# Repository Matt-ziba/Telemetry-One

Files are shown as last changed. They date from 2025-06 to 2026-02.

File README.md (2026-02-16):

## **Telemetry One** keyboard
*This is my submission for the second round of the HackPad YSWS event.*

#### Description:

The **Telemetry One** is a 75%, hot-swappable keyboard with an included accessory port (meant for a display but can be used for any I2C accessory :D ) and a case designed to fit into "sleeves", allowing for different looks while keeping the core the same. 

#### Design goal:

The main goal was to design a keyboard that I would actually like using, and that would follow a little bit of my design philosophy. I believe that as people, we grow and change over the years, and so should our equipment to better suit our needs and preferences. This idea, although not perfectly executed, is incorporated into the design of Telemetry One. The hot-swap sockets allow changing the switches at any point, so if I ever decide I no longer like tactile switches, and would rather switch to linear, I can do so! The I2C port, although very simple, allows for many different kinds of accessories to be connected to the keyboard. The ones that come to mind the most are things like displays, rotary encoders, haptic feedback, BLE modules for wireless connectivity or even connecting a macropad as an I2C slave device. The last important part is the case, which allows for mounting into different "sleeves", enabling the user to switch keyboard looks as they choose. Overall, I think I achieved my goal with the Telemetry One pretty well and I'm happy with how the design turned out.

#### Parts description:

The PCB itself is pretty decent, it also took the longest :D. The overall design isn´t too complex but I took my time really polishing it. I´m sure that I´ll find lots of flaws in it during assembly or during usage, but that´s just part of the process!

The case is pretty bare bones, but that is intentional. Instead of a full fledged case, I wanted something that could easily be mounted in different "sleeves" depending on the desired look. I have yet to model the "sleeve" designs I have in mind, but I do have a couple of ideas for them. The assembly of the case is pretty simple, with screws going from the bottom through the entirety of the case into the top part, which will have embedded nuts.

The firmware is absolute dogwater, that´s unfortunately not intentional :D. Yeah to be honest I procrastinated on the firmware until the last day and had to write it while hungover with not enough time to do proper research. I will definitely rewrite it once the keyboard actually arrives, as that will make debugging way easier. Currently it´s some weird ahh code that should probably work, but I honestly have no clue. 

## PCB Images

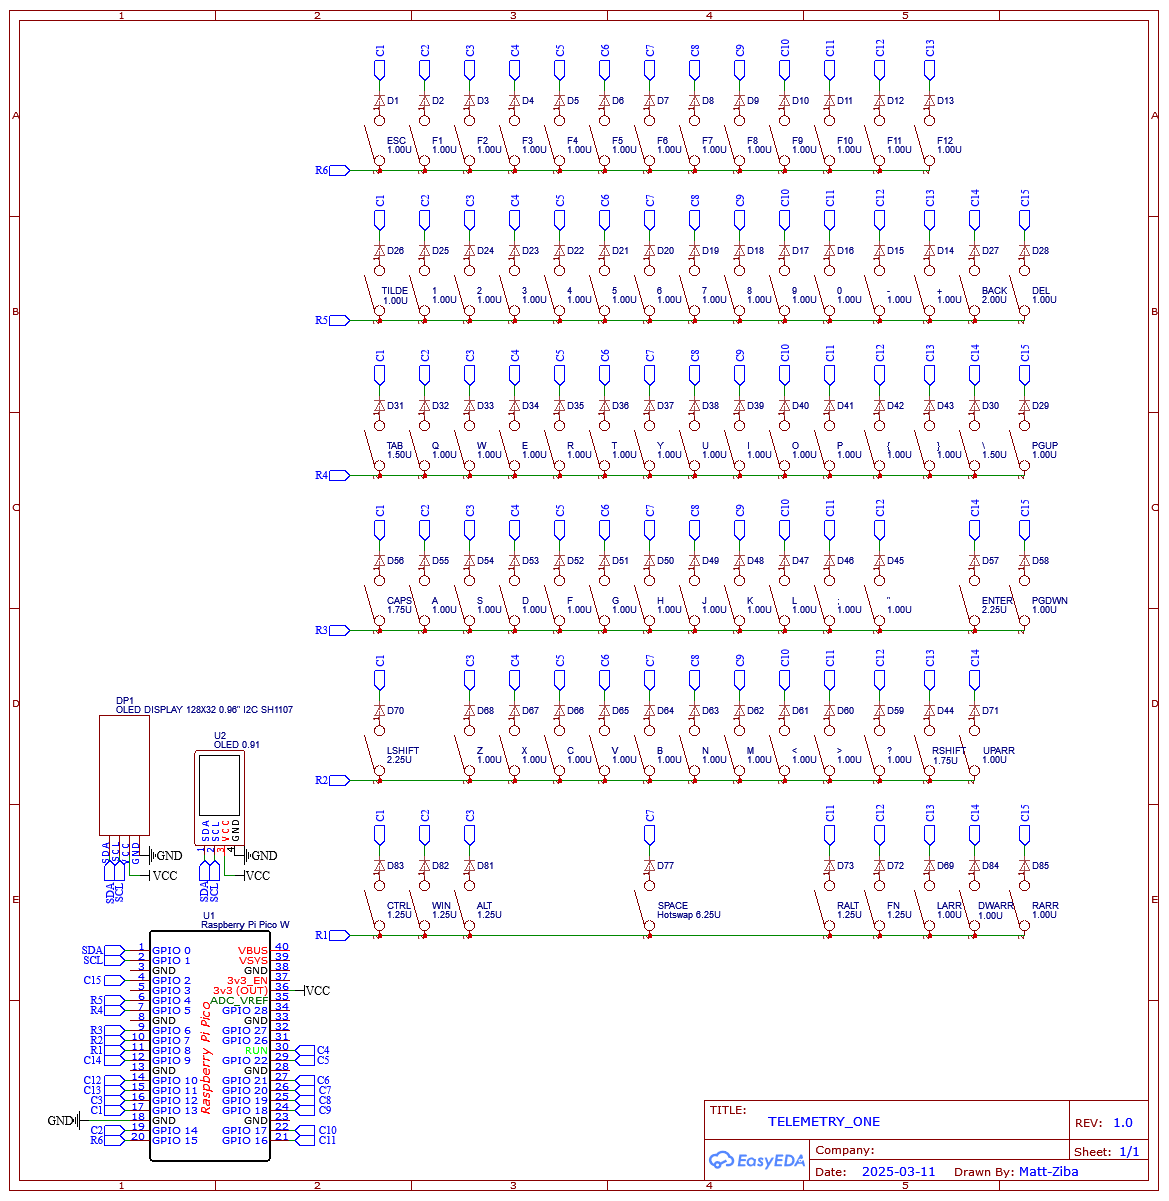
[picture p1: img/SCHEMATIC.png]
Schematic Screenshot

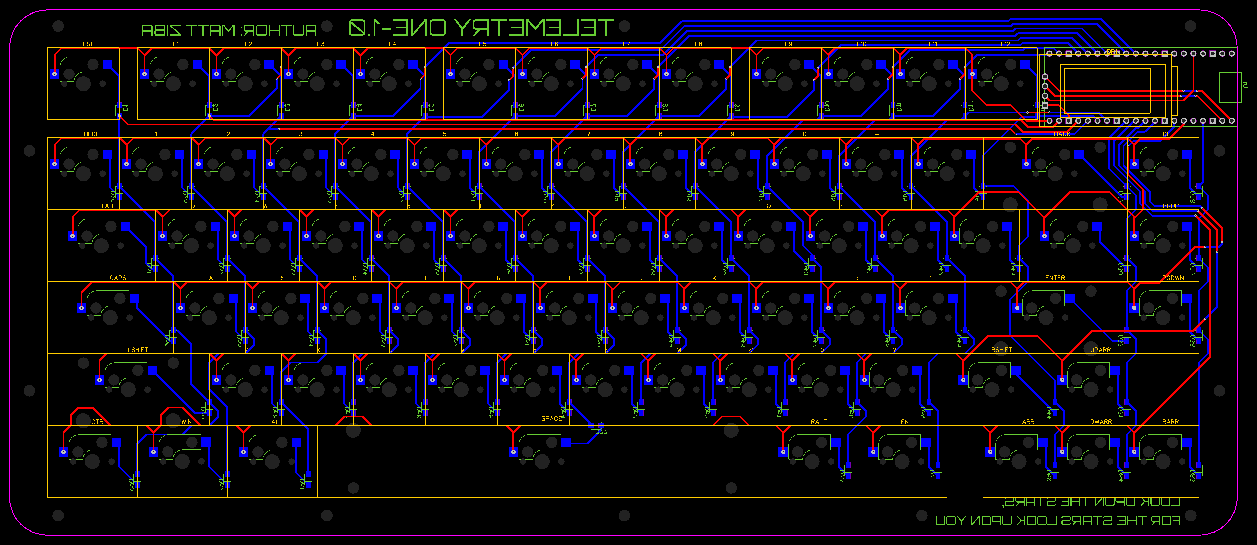
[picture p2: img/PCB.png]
PCB Screenshot

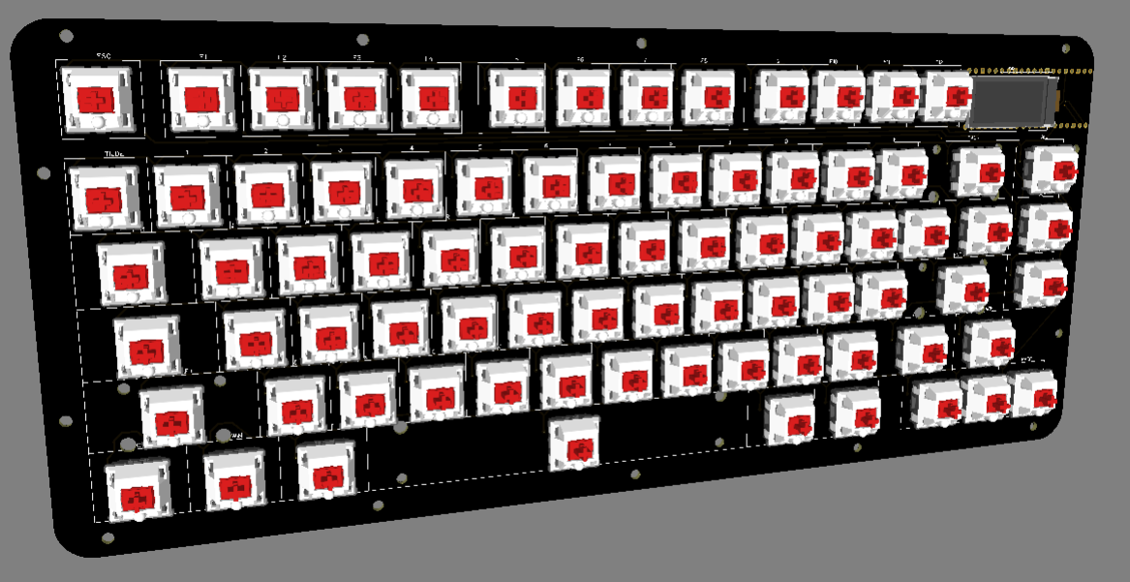
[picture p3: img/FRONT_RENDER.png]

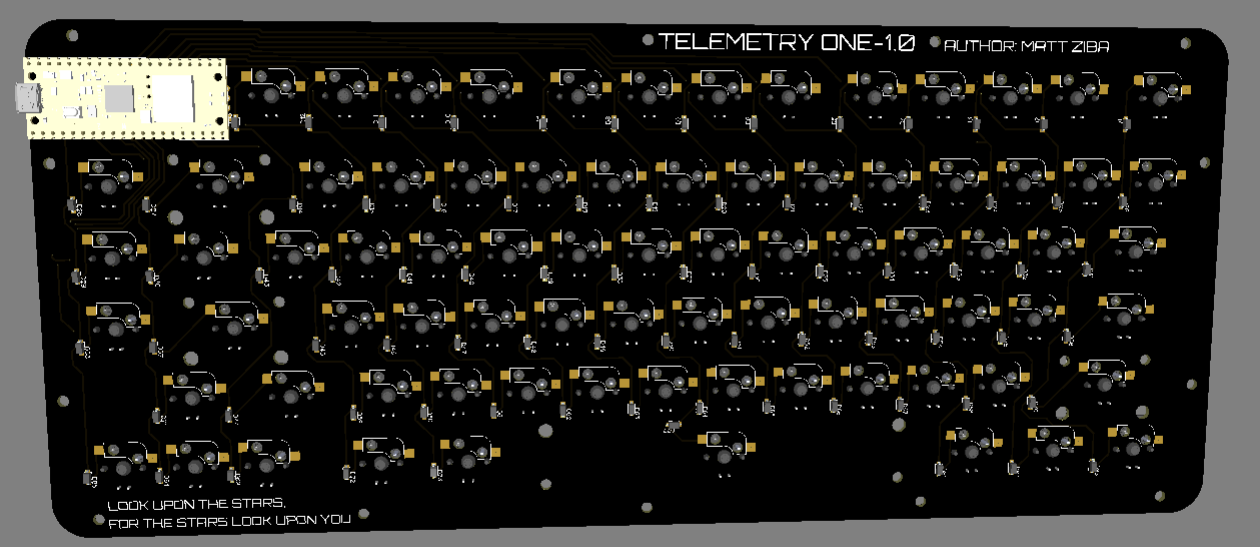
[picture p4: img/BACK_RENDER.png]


## Case Image

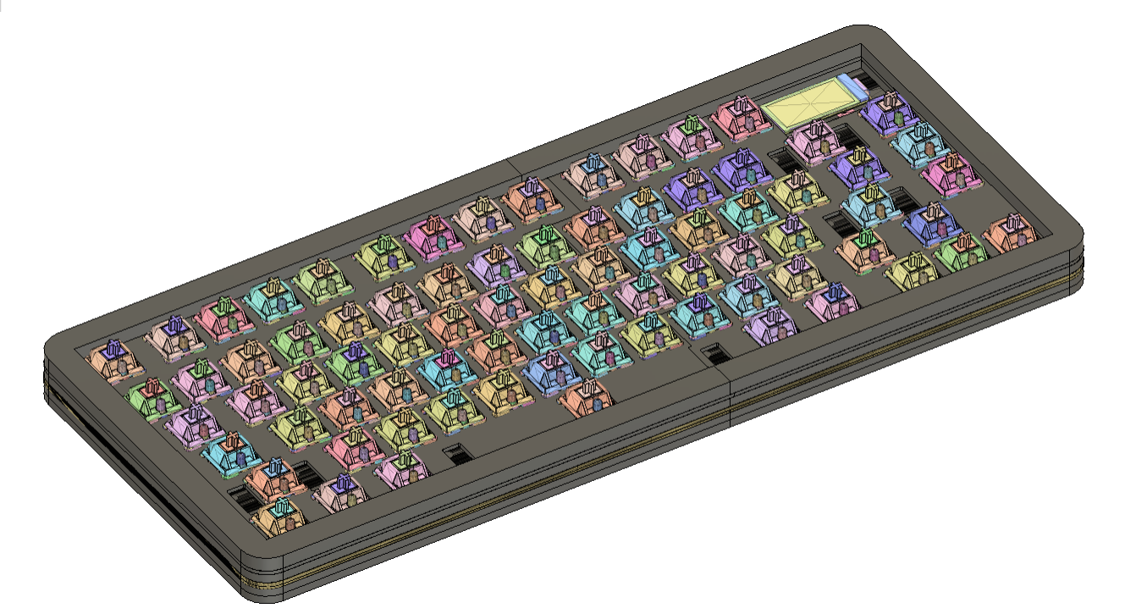
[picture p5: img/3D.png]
Case Screenshot


## BILL OF MATERIALS
| Item | Quantity | Price | Link |
|---|---|---|---|
| Akko V3 Creamy Blue Pro Switch | 1x 90pcs pack | 18USD (0.2USD per piece) | https://en.akkogear.com/product/akko-v3-cream-blue-pro-switch-45pcs/ |
| Kailh Hotswap sockets | 2x 50pcs pack | 16USD (0.16USD per piece) | https://splitkb.com/products/kailh-hotswap-sockets |
| TX AP stabilizers | 1x pack | 23USD (3USD over budget paid by me) | https://divinikey.com/products/tx-ap-stabilizers-rev-4 |
| Keycap Set from Aliexpress | 1x set | 22USD | https://www.aliexpress.com/item/1005007393936770.html |
| L1N4148 Diodes from LCSC | 2x 50pcs | 1.3USD (0.013USD per piece) | https://lcsc.com/product-detail/Switching-Diodes_LRC-L1N4148FT1G_C132821.html |
| 0.91" Display from LCSC | 1x | 2.3USD | https://lcsc.com/product-detail/OLED-Display_HS-HS91L02W2C01_C5248081.html |
| PCB | 1x (JLCPCB 5pcs minimum) | <20USD | N/A |
| Orpheus Pico board | 1x | N/A | N/A |

Materials cost in total: Around **100USD** (The materials in the BOM are a total 84USD, but I don't know how much the PCB will cost, or what the shipping costs will be, so I would rather have a little headroom)

I do not need the 3D printed parts, as I have access to a 3D printer and thus I don´t want to waste HackClub resources by requesting the parts when I can print them myself.  
I also don´t need fasteners, as I intentionally designed the keyboard around fasteners which I have at home.

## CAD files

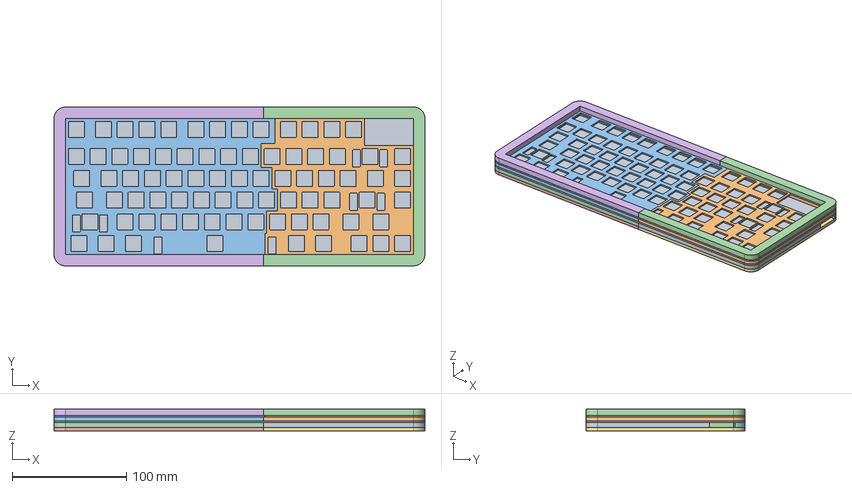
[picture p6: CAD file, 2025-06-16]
CAD/Telemetry_One.step
324.9 x 139.1 x 18.9 mm

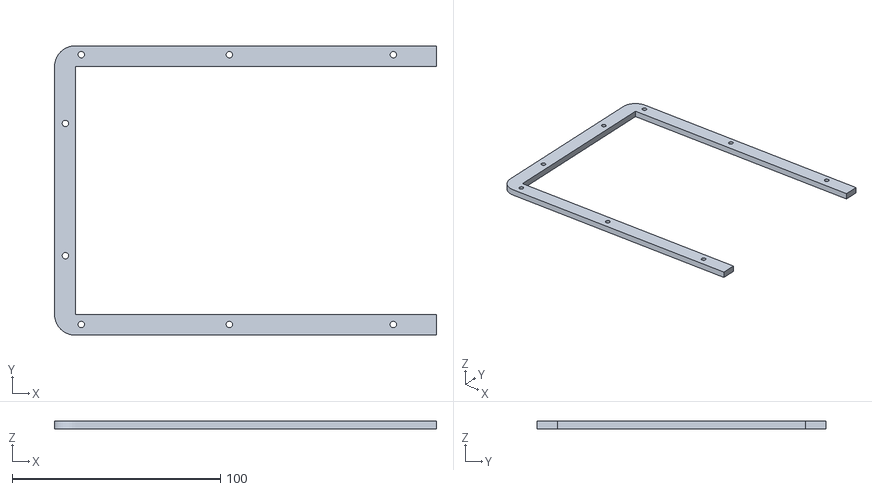
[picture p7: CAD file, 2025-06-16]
production/BOTSPACER.stl
183.4 x 139.0 x 4.00

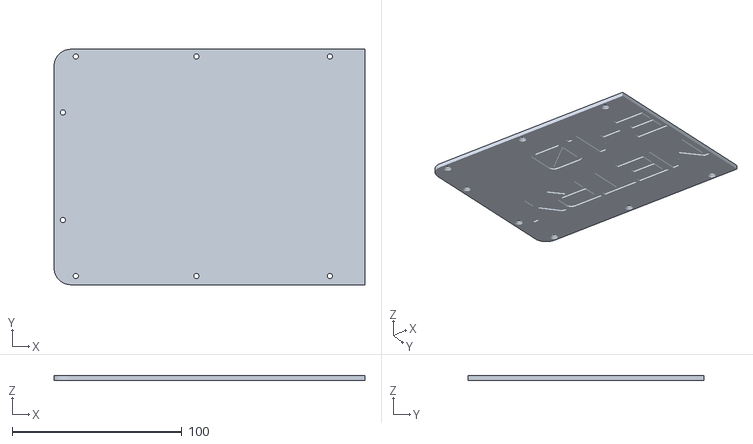
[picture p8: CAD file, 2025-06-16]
production/BOTPLATE.stl
183.4 x 139.0 x 3.10

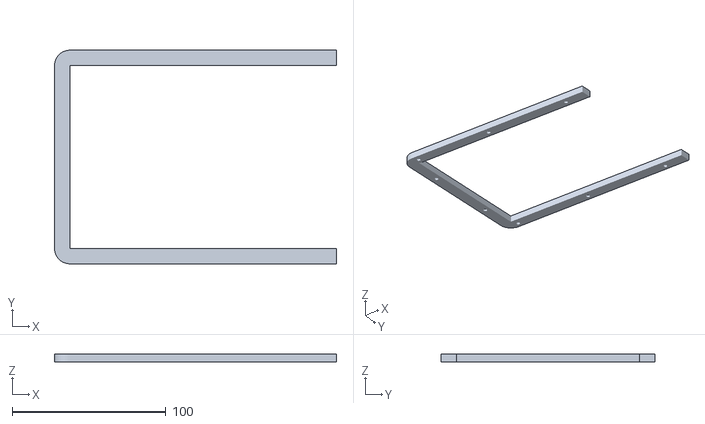
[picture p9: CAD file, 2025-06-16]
production/TOP.stl
183.4 x 139.0 x 5.35

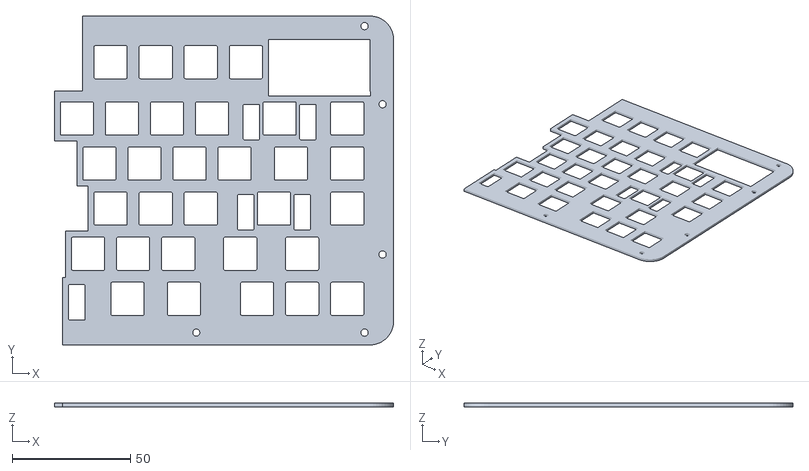
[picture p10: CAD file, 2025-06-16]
production/PLATE.stl
143.4 x 139.1 x 1.50

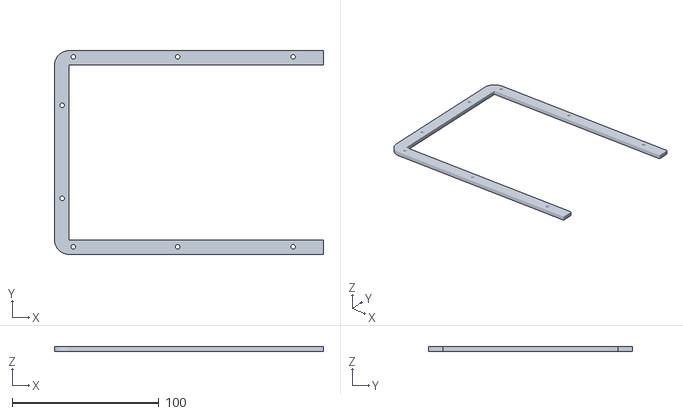
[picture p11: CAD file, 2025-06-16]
production/TOPSPACER.stl
183.4 x 139.0 x 3.40

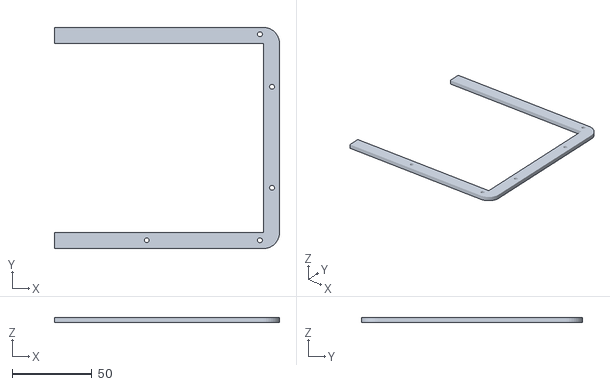
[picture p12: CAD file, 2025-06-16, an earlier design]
production/TOPSPACER (1).stl
141.4 x 139.0 x 3.40

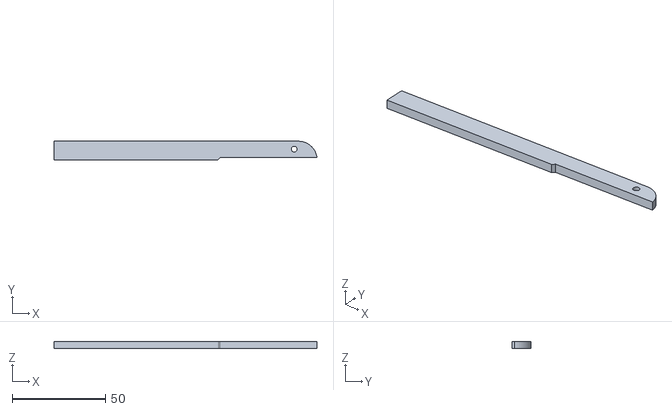
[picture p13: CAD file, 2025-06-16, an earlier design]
production/BOTSPACER (1).stl
141.4 x 10.0 x 4.00

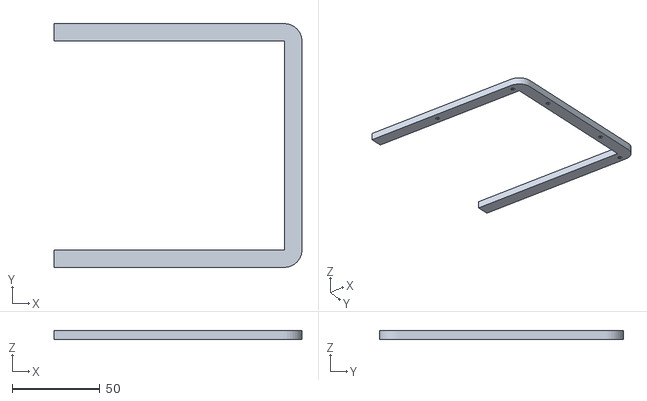
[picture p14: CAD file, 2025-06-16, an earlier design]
production/TOP (1).stl
141.4 x 139.0 x 5.35

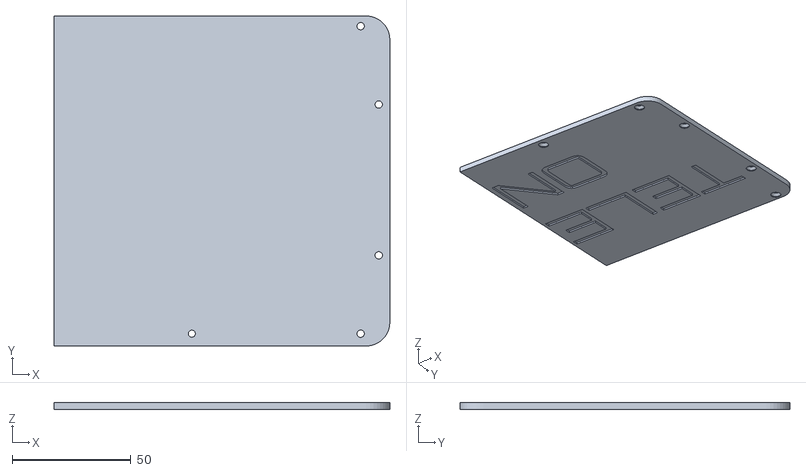
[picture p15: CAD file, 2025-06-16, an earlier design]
production/BOTPLATE (1).stl
141.4 x 139.0 x 3.10

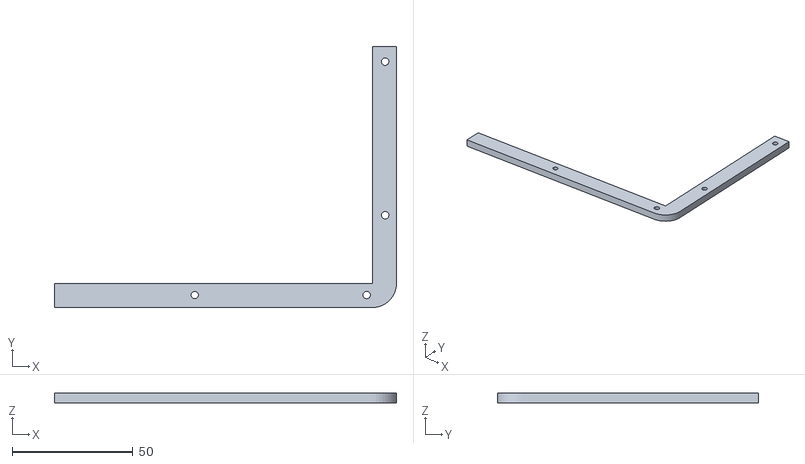
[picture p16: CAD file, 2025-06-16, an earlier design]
production/BOTSPACER (2).stl
141.4 x 108.0 x 4.00

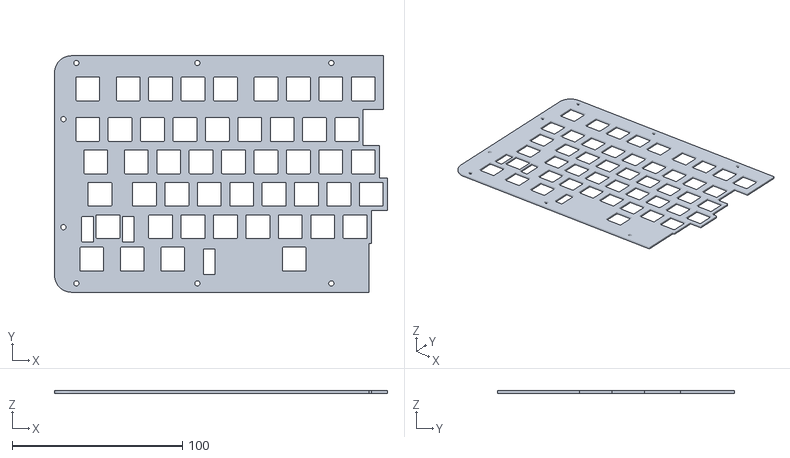
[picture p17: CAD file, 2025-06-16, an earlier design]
production/PLATE (1).stl
195.7 x 139.1 x 1.50

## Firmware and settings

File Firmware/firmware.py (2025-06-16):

import board
import digitalio
import time
from adafruit_matrixkeypad import Matrix_Keypad
from adafruit_hid.keyboard import Keyboard
from adafruit_hid.keycode import Keycode

rows = [board.GP8, board.GP7, board.GP6, board.GP5, board.GP4, board.GP15]
cols = [board.GP13, board.GP14, board.GP12, board.GP0, board.GP22, board.GP21, board.GP20, board.GP19, board.GP18, board.GP17, board.GP16, board.GP10, board.GP11, board.GP9, board.GP2]

row_pins = [digitalio.DigitalInOut(pin) for pin in rows]
column_pins = [digitalio.DigitalInOut(pin) for pin in cols]

keypad = Matrix_Keypad(row_pins, column_pins)

keyboard = Keyboard()

keymap = [
    [Keycode.ESC, Keycode.F1, Keycode.F2, Keycode.F3, Keycode.F4, Keycode.F5, Keycode.F6, Keycode.F7, Keycode.F8, Keycode.F9, Keycode.F10, Keycode.F11, Keycode.F12],
    [Keycode.GRAVE_ACCENT, Keycode.NUMBER_1, Keycode.NUMBER_2, Keycode.NUMBER_3, Keycode.NUMBER_4, Keycode.NUMBER_5, Keycode.NUMBER_6, Keycode.NUMBER_7, Keycode.NUMBER_8, Keycode.NUMBER_9, Keycode.NUMBER_0, Keycode.MINUS, Keycode.EQUALS, Keycode.BACKSPACE, Keycode.DELETE],
    [Keycode.TAB, Keycode.Q, Keycode.W, Keycode.E, Keycode.R, Keycode.T, Keycode.Y, Keycode.U, Keycode.I, Keycode.O, Keycode.P, Keycode.LEFT_BRACKET, Keycode.RIGHT_BRACKET, Keycode.BACKSLASH, Keycode.PAGE_UP],
    [Keycode.CAPS_LOCK, Keycode.A, Keycode.S, Keycode.D, Keycode.F, Keycode.G, Keycode.H, Keycode.J, Keycode.K, Keycode.L, Keycode.SEMICOLON, Keycode.QUOTE, None, Keycode.ENTER, Keycode.PAGE_DOWN],
    [Keycode.LEFT_SHIFT, None, Keycode.Z, Keycode.X, Keycode.C, Keycode.V, Keycode.B, Keycode.N, Keycode.M, Keycode.COMMA, Keycode.PERIOD, Keycode.FORWARD_SLASH, Keycode.RIGHT_SHIFT, Keycode.UP_ARROW, None],
    [Keycode.LEFT_CONTROL, Keycode.APPLICATION, Keycode.LEFT_ALT, None, None, None, Keycode.SPACE, None, None, None, Keycode.RIGHT_ALT, None, Keycode.LEFT_ARROW, Keycode.DOWN_ARROW, Keycode.RIGHT_ARROW]
]

while True:
    keys = keypad.pressed_keys
    if keys:
        for key in keys:
            for row in range(len(rows)):
                for col in range(len(cols)):
                    if keypad.keypad[row][col] == key:
                        keycode = keymap[row][col]
                        if keycode is not None:
                            keyboard.press(keycode)
                        break
            time.sleep(0.1) 
        keyboard.release_all()
    time.sleep(0.05)

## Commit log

2025-06-16 added BOM
    [BOM.csv]
2025-10-30 change BOM.csv
    [BOM.csv]
2025-10-30 Changed README.md BOM to a table format
